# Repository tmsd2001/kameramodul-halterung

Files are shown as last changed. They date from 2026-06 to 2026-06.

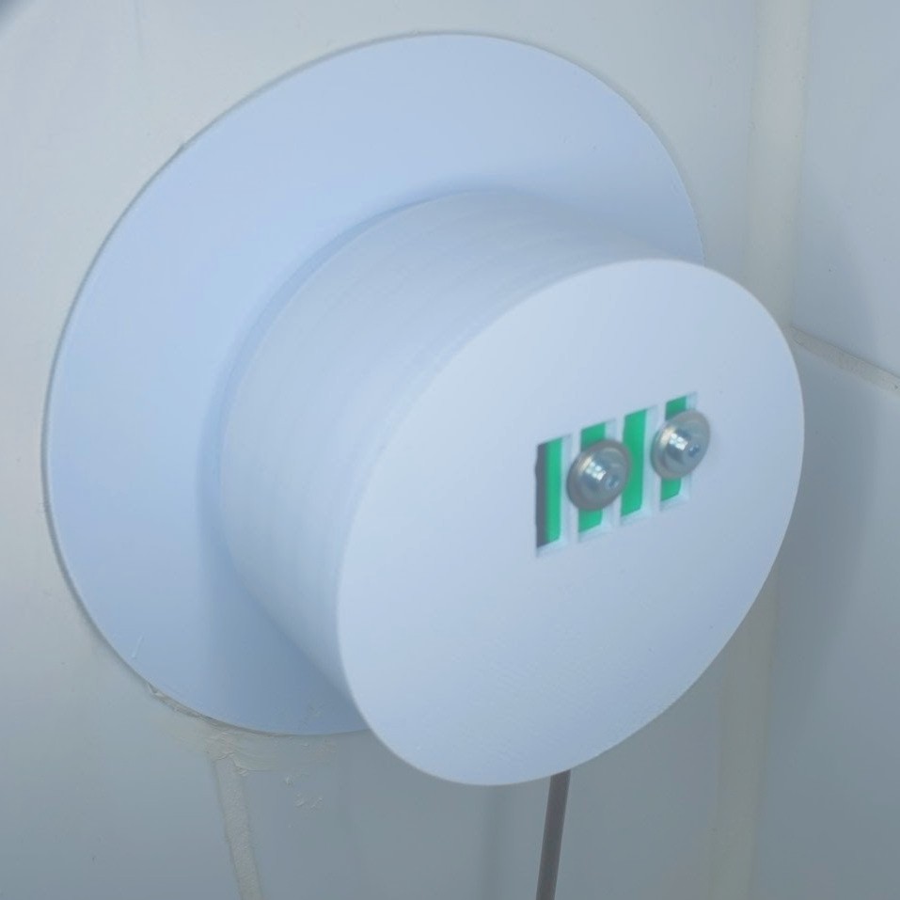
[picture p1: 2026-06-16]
referenzen/halter_komplett.jpg

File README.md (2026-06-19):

Reverse Engineering und Konstruktion einer modularen Kamerahalterung
Projektverantwortlicher: Thomas Drebert
Lizenz: MIT License
Technologien & Werkzeuge: OpenSCAD, Git / GitHub, Messschieber, Anycubic i3 Mega

1. Projektziel

Ziel des Projekts war die Entwicklung, Konstruktion und Fertigung einer passgenauen, dreiteiligen Halterung für ein spezifisches Kameramodul. Da vom Hersteller keine detaillierten CAD-Daten oder technischen Zeichnungen zur Verfügung gestellt wurden, musste die Geometrie des Bauteils vollständig selbst ermittelt und digital rekonstruiert werden.

2. Methodik und Umsetzung

Datenerfassung und Reverse Engineering:
Im ersten Schritt wurden die physischen Abmessungen des Kameragehäuses manuell mit einem Messschieber erfasst. Da das Kunststoffgehäuse über schwer messbare Kanten und komplexe Linsen- sowie LED-Anordnungen verfügt, wurden die manuellen Messwerte durch den fotogrammetrischen Abgleich mit Originalaufnahmen validiert und korrigiert.
Erstellung der technischen Dokumentation:
Aus den ermittelten Rohdaten wurde eine normgerechte, zweidimensionale technische Zeichnung inklusive Seitenansicht erstellt. Diese diente als verlässliche Datengrundlage für die anschließende 3D-Modellierung.
Parametrisches CAD-Modell als Digitaler Zwilling:
Auf Basis der technischen Zeichnung wurde das Kameramodul in OpenSCAD parametrisch nachgebaut. Dieser "digitale Zwilling" fungierte im weiteren Verlauf als exaktes Referenzmodell.
Konstruktion der Halterung:
Anschließend wurde eine modulare, dreiteilige Halterung (bestehend aus Basis, Schwenkarm und Klemmung) in OpenSCAD programmiert. Durch die Einbindung des Referenzmodells in die Entwicklungsumgebung konnte digital verifiziert werden, dass die Kamera kollisionsfrei sitzt und Passungsprobleme vor dem Druck ausgeschlossen sind.
Versionskontrolle und Publikation:
Der gesamte Quellcode der parametrischen Modelle sowie die technischen Dokumentationen wurden in einem Git-Repository strukturiert und versioniert. Das Projekt wurde abschließend als Open-Source-Hardware unter der MIT-Lizenz auf GitHub veröffentlicht.

3. Ergebnis

Das Resultat ist eine vollständig dokumentierte, versionierte und parametrisch anpassbare 3D-Druck-Konstruktion. Der gewählte Workflow unterstreicht eine systematische, lösungsorientierte Herangehensweise an Problemstellungen, bei denen primäre Konstruktionsdaten fehlen.

4. Wichtiger Hardware- und Betriebshinweis (Beleuchtung)

Während ausgiebiger, mehrstündiger Testphasen mit der AIS-Kamera stellte sich heraus, dass die integrierten LEDs der Kamera keine stabilen Datenlieferungen für die Ziffernerkennung ermöglichten (beispielsweise durch störende Reflexionen auf dem Glas des Zählers). 

**Empfohlene Modifikation für einen stabilen Betrieb:**
* **Interne Beleuchtung deaktivieren:** Die integrierten LEDs der Kamera sollten vollständig abgeschaltet werden.
* **Externe Lichtquelle nutzen:** Die Ausleuchtung des Zählers über eine separate, externe LED-Lichtquelle brachte den sofortigen Erfolg. Seit dieser Anpassung erkennt die Kamera die Zahlen absolut zuverlässig und stabil.

Dieser Aspekt sollte beim Nachbau und der Ausrichtung der Halterung unbedingt berücksichtigt werden. Passende Optimierungen und Halterungen für externes Zubehör werden im Ordner `scad/zubehoer.scad` gepflegt.

5. Haftungsausschluss und Mitwirkung (Community)

Haftungsausschluss:

Die hier bereitgestellten Modelle, Maße und Zeichnungen basieren auf manuellen Messungen an einem Originalbauteil und wurden nach bestem Gewissen erstellt. Da es sich um ein Reverse-Engineering-Projekt handelt, wird keine Garantie für die absolute Richtigkeit der Maße, die Passgenauigkeit oder eventuelle Schäden übernommen, die durch den Nachdruck oder die Verwendung der Halterung entstehen. Die Nutzung der Daten und Modelle erfolgt vollständig auf eigene Gefahr. Ergänzend gilt der Haftungsausschluss der beiliegenden MIT-Lizenz.
Work in Progress & Beteiligung:
Dieses Projekt befindet sich weiterhin in der Entwicklung und kann noch Fehler oder ungenaue Toleranzen enthalten. Die Veröffentlichung als Open-Source-Projekt dient ausdrücklich dem Zweck, das Modell gemeinsam zu optimieren.
Die Community ist herzlich eingeladen, bei der Fehlerbeseitigung und Verbesserung zu helfen:
Wer Abweichungen bei den Maßen feststellt oder generelle Passungsprobleme hat, kann dies gerne über die "Issues"-Funktion auf GitHub melden.
Direkte Code-Korrekturen und Geometrie-Optimierungen können jederzeit als "Pull Request" eingereicht werden.

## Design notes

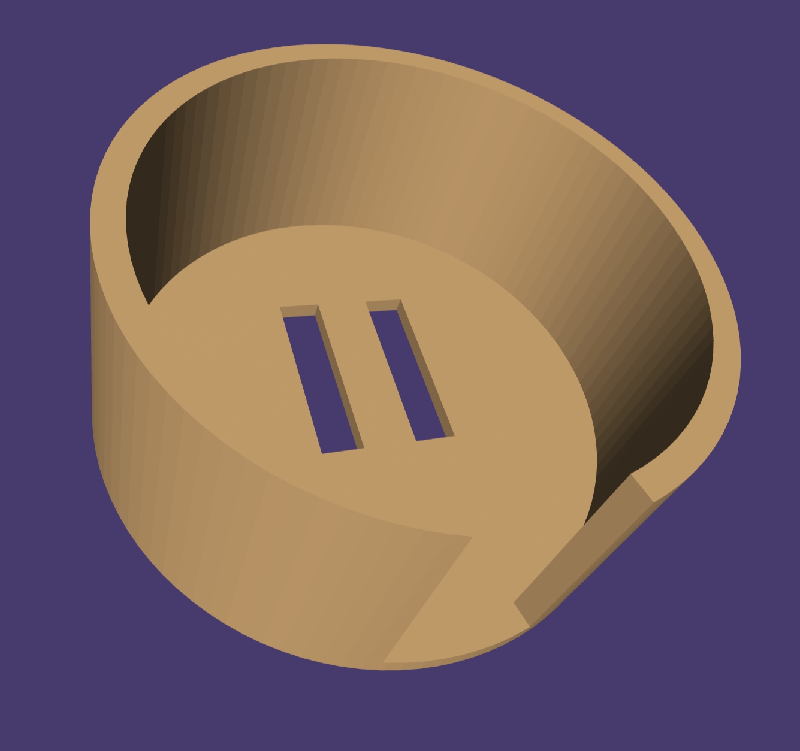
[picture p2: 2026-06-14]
referenzen/halter_teil2.jpg

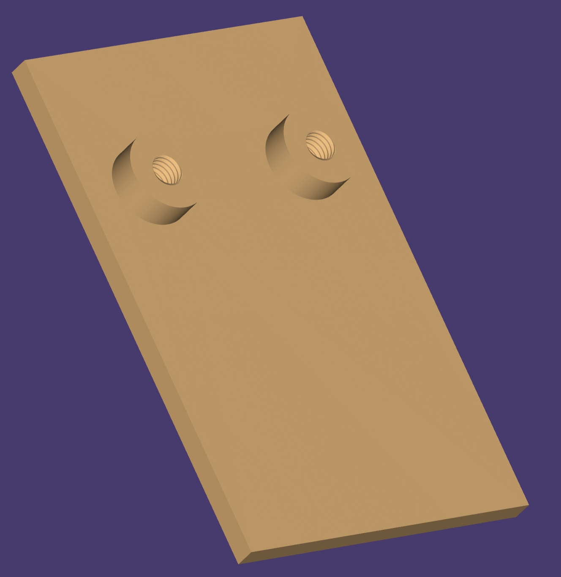
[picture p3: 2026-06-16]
referenzen/halter_teil3.jpg

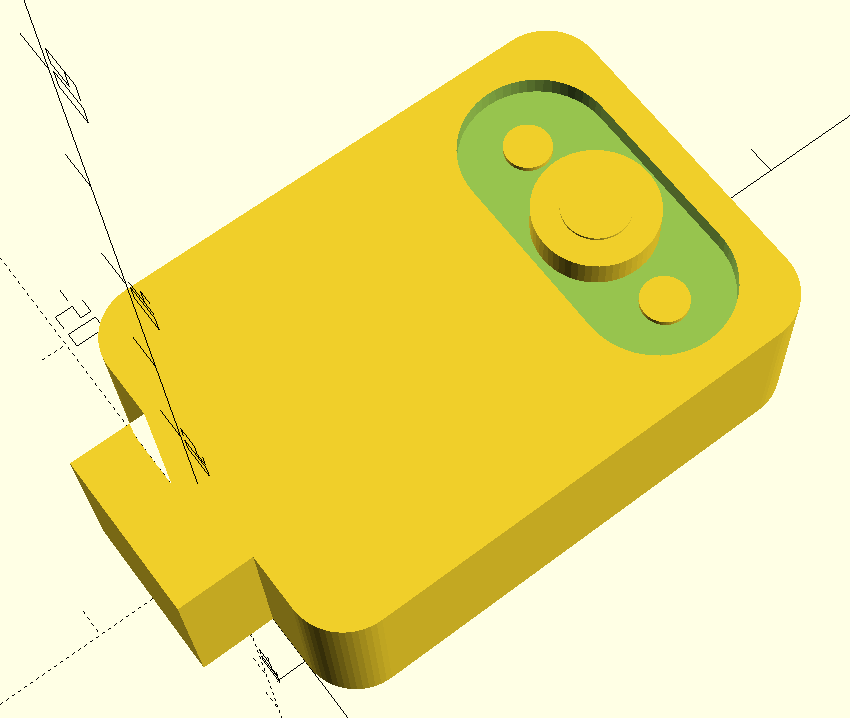
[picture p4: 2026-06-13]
referenzen/kamera_3D_modell.png

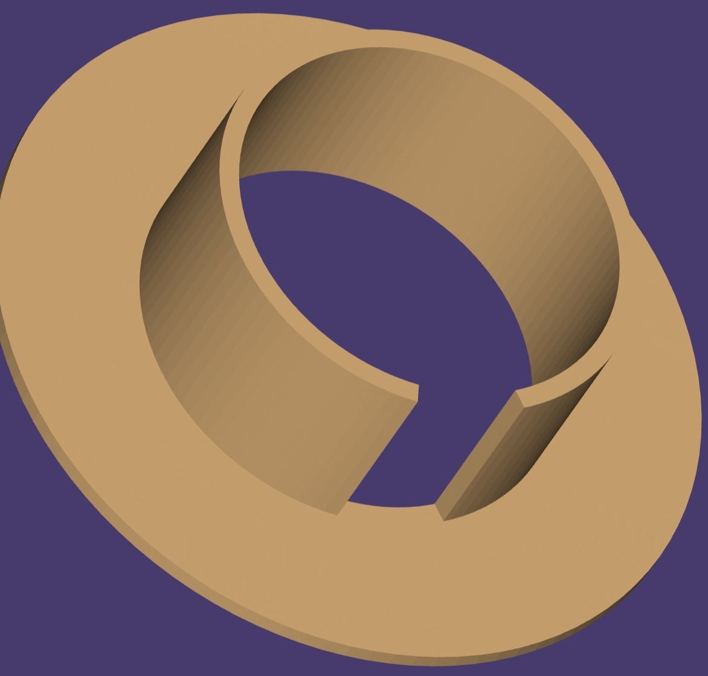
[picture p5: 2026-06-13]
referenzen/halter_teil1.jpg

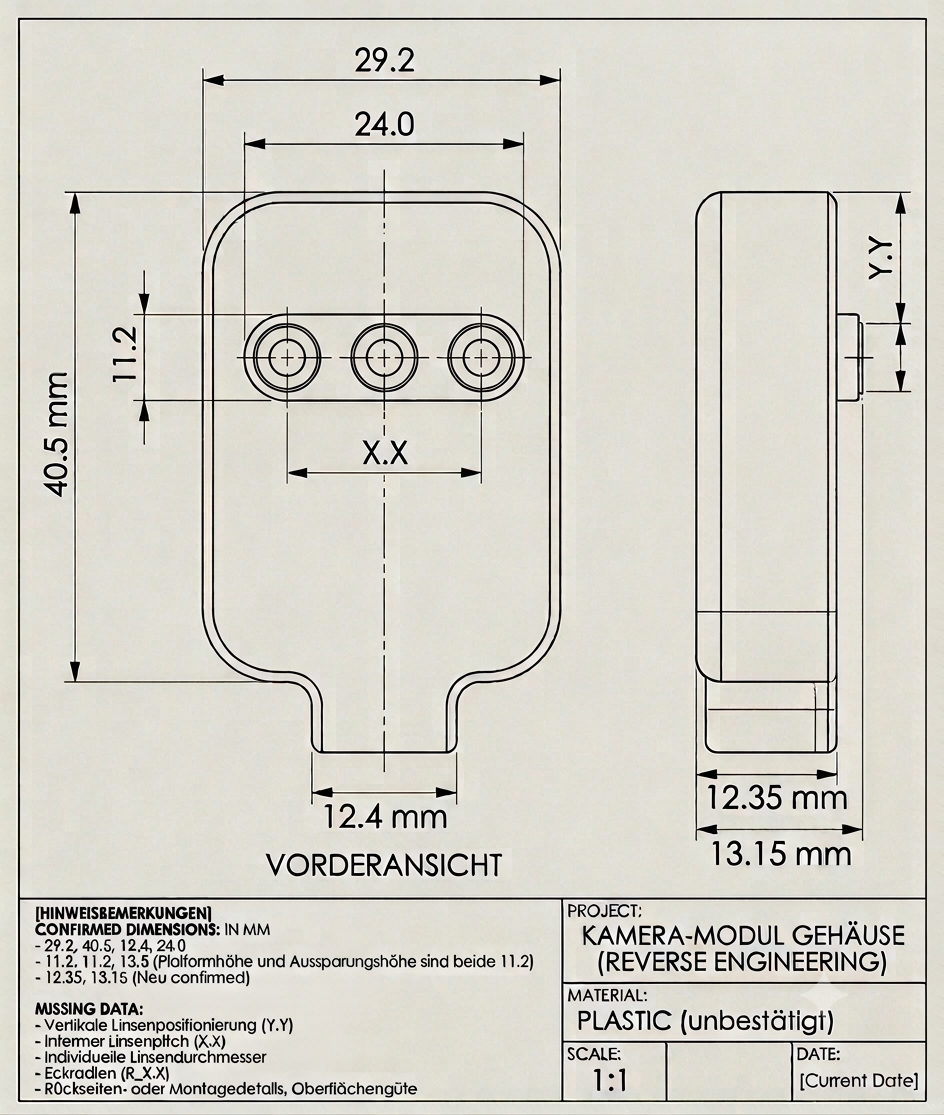
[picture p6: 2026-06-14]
referenzen/zeichnung_kamera.png

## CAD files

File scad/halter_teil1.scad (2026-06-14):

//
// Parameters
//

// Tapered adapter section
bottom_inner_radius = 65;
top_inner_radius    = 36;
cone_height         = 3;

// Cylindrical section
inner_radius        = 36;
outer_radius        = 39.7;
cylinder_height     = 40;

// Wall thickness
wall_thickness      = 2;

// Opening
missing_angle       = 30;   // Angular section to remove

$fn = 100;                  // High resolution for smooth curves


//
// Hollow tapered section
//
difference() {

    // Outer cone
    cylinder(
        h = cone_height,
        r = bottom_inner_radius + wall_thickness
    );

    // Inner cavity
    translate([0, 0, -1]) {
        cylinder(
            h = cone_height + 2,
            r = top_inner_radius
        );
    }
}


//
// Hollow cylinder with opening
//
difference() {

    //
    // Main hollow cylinder
    //
    difference() {

        // Outer wall
        cylinder(
            h = cylinder_height,
            r = outer_radius
        );

        // Inner cavity
        translate([0, 0, -1]) {
            cylinder(
                h = cylinder_height + 2,
                r = inner_radius
            );
        }
    }

    //
    // Remove pie-shaped section
    //
    translate([0, 0, -1]) {

        linear_extrude(height = cylinder_height + 2) {

            pie_slice_2d(
                r = outer_radius + 5,
                angle = missing_angle
            );
        }
    }
}


//
// 2D pie-slice module
// Origin located at [0, 0]
//
module pie_slice_2d(r, angle) {

    intersection() {

        circle(r = r);

        polygon(
            points = concat(
                [[0, 0]],
                [
                    for (a = [0 : 5 : angle])
                        [r * 2 * cos(a), r * 2 * sin(a)]
                ],
                [[r * 2 * cos(angle), r * 2 * sin(angle)]]
            )
        );
    }
}

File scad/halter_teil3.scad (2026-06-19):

include <BOSL2/std.scad>;
include <BOSL2/screws.scad>;


//
// Parameters
//
base_width         = 29;
base_depth         = 45;
base_thickness     = 2;

mount_spacing      = 16;
mount_y_position   = 10;

mount_radius       = 3.5;
mount_height       = 4;
mount_z_position   = 1.8;

thread_spec        = "M3";
thread_length      = 15.5;
thread_z_position  = 2;

$fn = 100;                  // High resolution for smooth surfaces


//
// Mounting plate with threaded holes
//
difference() {

    //
    // Positive geometry
    //
    union() {

        // Base plate
        cube(
            [base_width, base_depth, base_thickness],
            center = true
        );

        // Mounting bosses
        for (x = [-mount_spacing / 2, mount_spacing / 2]) {

            translate([x, mount_y_position, mount_z_position]) {

                cylinder(
                    h = mount_height,
                    r = mount_radius,
                    center = true
                );
            }
        }
    }

    //
    // Threaded holes
    //
    for (x = [-mount_spacing / 2, mount_spacing / 2]) {

        translate([x, mount_y_position, thread_z_position]) {

            // BOSL2 uses 'spec' to define thread size.
            // thread=true generates a real threaded hole.
            // anchor=CENTER aligns the feature to the local origin.
            screw_hole(
                spec   = thread_spec,
                l      = thread_length,
                thread = true,
                anchor = CENTER
            );
        }
    }
}

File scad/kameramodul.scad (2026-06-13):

// =================================================================
// OpenSCAD Modell: Kameramodul Gehäuse
// Basierend auf den korrigierten technischen Zeichnungen und Herstellerangaben
// =================================================================

$fn = 60; // Erhöht die Segmentanzahl für perfekt runde Kreise und Zylinder

// --- PARAMETER (Alle Maße in mm) ---

// Hauptabmessungen laut Hersteller & Skizzenabgleich
gesamt_breite      = 29.0;  // Herstellerangabe
gehaeuse_hoehe     = 40.5;  // Eigene Messung des Hauptkörpers
stufe_hoehe        = 5.7;   // Berechnet aus Herstellertotal (46.2mm) - Hauptkörper (40.5mm)
stufe_breite       = 12.4;  // Breite des unteren Kabelhalses
gehaeuse_dicke     = 12.35; // Gehäusedicke ohne Linse
gesamt_dicke       = 13.15; // Gesamtdicke inklusive Linse
linsen_ueberstand  = gesamt_dicke - gehaeuse_dicke; // 0.8 mm Überstand über Gehäusefront

// Positionierung der optischen Achse (Letzte Korrekturauflage)
linsen_y_von_oben  = 8.0;   // Abstand von Gehäuseoberkante bis Linsenmitte
linsen_y_pos       = gehaeuse_hoehe - linsen_y_von_oben; // Absolute Y-Position im Koordinatensystem

// Abmessungen der Aussparung (Kapselform / Frontglas)
recess_breite      = 24.0;  // Gesamte horizontale Ausdehnung der Aussparung
recess_hoehe       = 11.2;  // Vertikale Höhe der Aussparung
recess_tiefe       = 1.5;   // *HINWEIS: Angenommener Wert, da Tiefe nicht explizit bemaßt*

// Details der Kamera-Optik & LEDs
kamera_dm_aussen   = 9.0;   // Äußerer Ring der Kameralinse
kamera_dm_innen    = 5.0;   // Innerer Linsendurchmesser
led_abstand_x      = 7.5;   // Pitch von Gehäusemitte zu den LED-Mittelpunkten (links/rechts je 7.5mm)
led_durchmesser    = 3.5;   // *HINWEIS: Sinnvoller Richtwert für LEDs, da Durchmesser nicht explizit bemaßt*

// Geometrie-Optionen
eckradius_gehaeuse = 4.0;   // Rundung der vier Hauptgehäuseecken


// --- GEOMTRIE-MODULE ---

module gehaeuse_2d_profil() {
    // Hauptkörper des Gehäuses (wird im Ursprung auf Y=0 aufgesetzt)
    translate([-gesamt_breite/2 + eckradius_gehaeuse, eckradius_gehaeuse])
        minkowski() {
            square([gesamt_breite - 2*eckradius_gehaeuse, gehaeuse_hoehe - 2*eckradius_gehaeuse]);
            circle(r=eckradius_gehaeuse);
        }
    
    // Untere Stufe (Kabelhals)
    translate([-stufe_breite/2, -stufe_hoehe])
        square([stufe_breite, stufe_hoehe + 0.1]); // 0.1mm Überlappung verhindert Non-Manifold-Fehler
}

module linsen_aussparung_2d() {
    // Berechnet den Abstand der beiden Kreiselemente für die Kapselform
    recess_zentrum_abstand = (recess_breite - recess_hoehe) / 2;
    translate([0, linsen_y_pos]) {
        hull() {
            translate([-recess_zentrum_abstand, 0]) circle(d=recess_hoehe);
            translate([recess_zentrum_abstand, 0]) circle(d=recess_hoehe);
        }
    }
}


// --- 3D-AUFBAU (CSG-Operationen) ---

difference() {
    // 1. Hauptextrusion des Gehäusekörpers
    linear_extrude(height = gehaeuse_dicke) {
        gehaeuse_2d_profil();
    }
    
    // 2. Abzug der vorderen Kapsel-Aussparung für die Glasfront
    translate([0, 0, gehaeuse_dicke - recess_tiefe])
        linear_extrude(height = recess_tiefe + 0.1)
            linsen_aussparung_2d();
}

// 3. Aufbau der hervorstehenden Kameralinse
translate([0, linsen_y_pos, gehaeuse_dicke - recess_tiefe]) {
    // Äußerer Linsenzylinder
    cylinder(d = kamera_dm_aussen, h = recess_tiefe + linsen_ueberstand);
    
    // Innere optische Linse (wird minimal höher gesetzt zur visuellen Trennung)
    translate([0, 0, recess_tiefe + linsen_ueberstand])
        cylinder(d = kamera_dm_innen, h = 0.2);
}

// 4. Andeutung der LEDs innerhalb der Aussparung
translate([0, linsen_y_pos, gehaeuse_dicke - recess_tiefe]) {
    // Linke LED
    translate([-led_abstand_x, 0, 0])
        cylinder(d = led_durchmesser, h = 0.4);
    
    // Rechte LED
    translate([led_abstand_x, 0, 0])
        cylinder(d = led_durchmesser, h = 0.4);
}

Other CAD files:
scad/halter_teil2.scad

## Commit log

2026-06-13 Initiale Projektstruktur und Referenzmodell
2026-06-13 Erste Version
    [kameramodul.scad]
2026-06-14 Refactor OpenSCAD model and standardize code structure
    - Translate variable names and comments to English
    - Improve code organization and readability
    - Rename pie slice module for clarity
    - Remove unused parameters
    - Standardize formatting and indentation
    - Add consistent section headers and documentation
    [halter_teil1.scad]
2026-06-14 refactor: improve OpenSCAD mounting bracket structure and naming
    - Translate comments and variables to English
    - Introduce configurable parameters
    - Standardize formatting and documentation
    - Prepare geometry for easier maintenance
    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
    [halter_teil3.scad]
2026-06-16 Geometry adapted to the camera probe.
2026-06-16 First photo of the complete mount
2026-06-19 refactor: standardize mounting plate code structure
    - Replace duplicated geometry with loops
    - Improve readability and maintainability
    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
    [halter_teil3.scad]
2026-06-19 README um wichtigen Beleuchtungshinweis für die AIS-Kamera erweitert
